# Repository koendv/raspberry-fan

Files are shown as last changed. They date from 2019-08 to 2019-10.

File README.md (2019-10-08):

# LTC1695 Raspberry Fan Controller

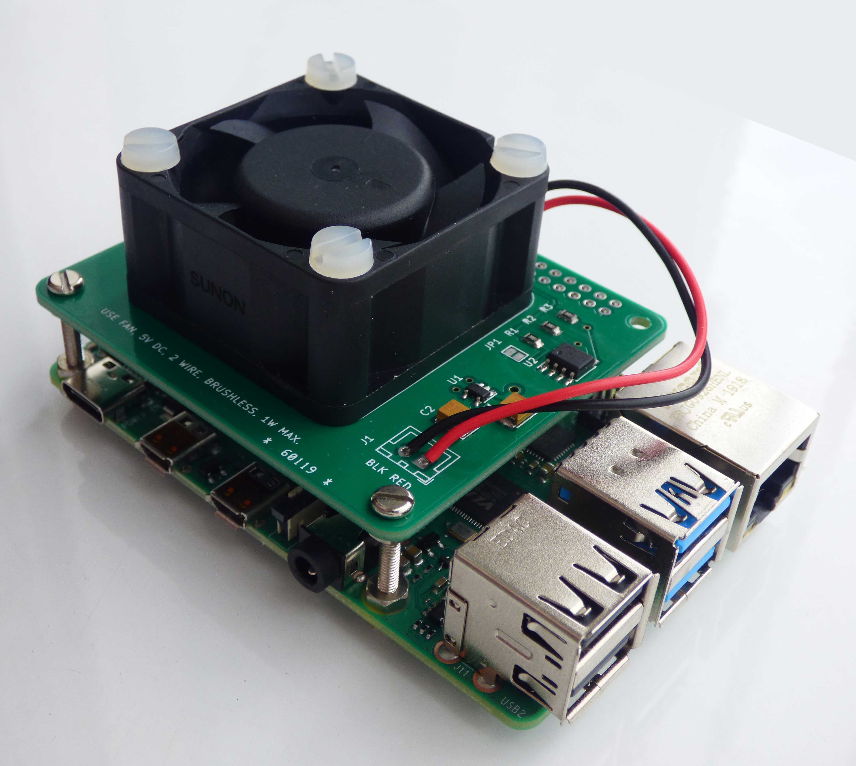
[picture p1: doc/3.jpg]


This is a fan speed controller for the Raspberry Pi. There is a smaller, cheaper version of the same controller [here](https://github.com/koendv/minimal_raspberry_fan).

## Hat

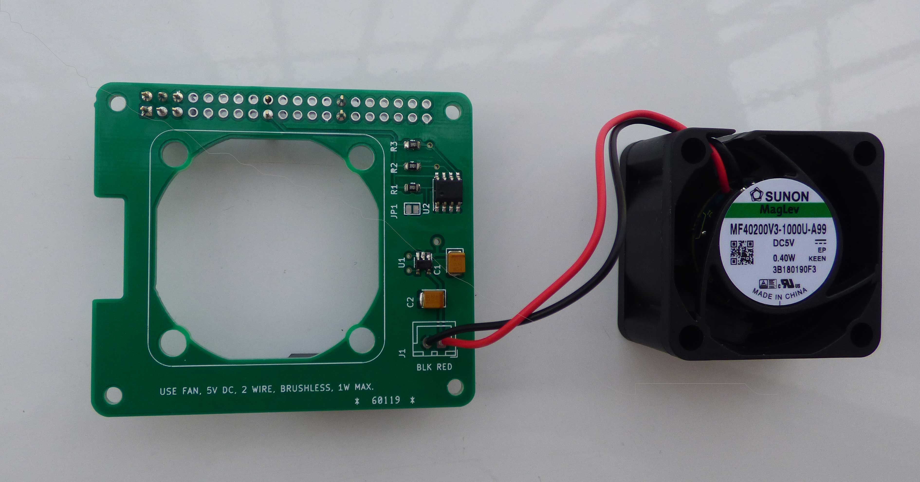
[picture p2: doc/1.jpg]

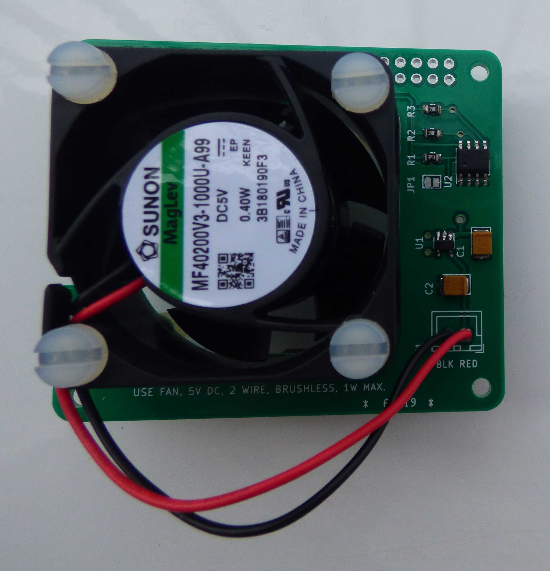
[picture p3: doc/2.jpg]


If you look at the [schematic](doc/schematic.pdf) you'll see the *hat* contains only two ic's: U1, an LTC1695 fan controller, and U2, a 24c32 EEPROM. The data in the EEPROM allows Raspbian to identify the hat. If you are making this for yourself, you can safely leave the EEPROM out.  That leaves us with the following components: 

Quant.|Item
---|--
1|LTC1695CS5  I2C Fan Speed Controller, SOT-23
2|KEMET T494B475K020AT Tantalum Capacitor, SMD 20V 4.7uF 1311 10% ESR=1 Ohms
1|Adafruit Accessories Header for Raspberry Pi
1|Sunon MF40200V3-1000U-A99 DC Fan 40mm, 5V.

The fan is 40mm, 5V DC, brushless, 2 wire, **1W max**. 
Adafruit has two GPIO headers for Raspberry, product numbers [1992](https://www.adafruit.com/product/1992) (tall, 16.5 mm) and  [2243](https://www.adafruit.com/product/2243) (short, 5.0 mm). Choose the one that clears the heatsink of the processor. 
## Installation
Enable i2c bus 1 clicking on the raspberry icon -> Preferences -> Raspberry Pi Configuration -> Interfaces -> i2c.
If you scan the i2c bus, you ought to see the fan controller at address 0x74:
```
koen@raspberrypi:~ $ sudo i2cdetect -r -y 1
     0  1  2  3  4  5  6  7  8  9  a  b  c  d  e  f
00:          -- -- -- -- -- -- -- -- -- -- -- -- -- 
10: -- -- -- -- -- -- -- -- -- -- -- -- -- -- -- -- 
20: -- -- -- -- -- -- -- -- -- -- -- -- -- -- -- -- 
30: -- -- -- -- -- -- -- -- -- -- -- -- -- -- -- -- 
40: -- -- -- -- -- -- -- -- -- -- -- -- -- -- -- -- 
50: -- -- -- -- -- -- -- -- -- -- -- -- -- -- -- -- 
60: -- -- -- -- -- -- -- -- -- -- -- -- -- -- -- -- 
70: -- -- -- -- 74 -- -- --                         
koen@raspberrypi:~ $ 
```
You can switch the fan completely on:
```
i2cset -y 1 0x74 63
```
completely off:
```
i2cset -y 1 0x74 0
```
or something in between:
```
i2cset -y 1 0x74 32
```
At low speeds, the fan might need a little extra push to get going. If you add 64 to the speed the fan will run at full speed for 0.25s, then slow down to the normal speed. As an example
```
i2cset -y 1 0x74 84
```
runs the  fan at the full 5V for a quarter second to get the fan moving, then drops to 1.56V for normal operation.

Lastly, you can read the fan controller status:
```
i2cget -y 1 0x74 
```

Value | Status
--------|--------
0|ok
64|thermal shutdown (T > 155 degree C)
128|overcurrent (I > 390mA)
192|thermal shutdown *and* overcurrent

## Running

The ```raspbian``` directory contains ```fanctl.py```, a python script which you can run either interactively or in the background. Feel free to modify the script as you wish. The values for *fan_min* and *fan_boost* are for the fan I'm using. The values  *temp_min* and *temp_max* represent personal choices. Once you are happy with the values, you can add the fan controller to ```/etc/rc.local``` so the fan starts up at boot:
```
/usr/local/bin/fanctl.py &
```

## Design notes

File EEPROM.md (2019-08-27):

# LTC1695 Raspberry Fan Controller

You can safely drop the EEPROM from the hat if you don't mind adding a daemon to /etc/rc.local yourself. Still, for those curious, this documents how to write the eeprom. 

## Writing the EEPROM
The fan controller is connected to i2c bus 1, while the configuration eeprom is connected to i2c bus 0. Enable i2c bus 1  in *Raspberry Pi Configuration -> Interfaces -> i2c*. To enable i2c bus 0 as well, add this line to /boot/config.txt and reboot:
```
dtparam=i2c_arm=on
dtparam=i2c_vc=on
```
Now you should be able to detect the configuration EEPROM on i2c bus 0, and the fan controller on i2c bus 1:
```
root@raspberrypi:/home/koen# i2cdetect -y 0
     0  1  2  3  4  5  6  7  8  9  a  b  c  d  e  f
00:          -- -- -- -- -- -- -- -- -- -- -- -- -- 
10: -- -- -- -- -- -- -- -- -- -- -- -- -- -- -- -- 
20: -- -- -- -- -- -- -- -- -- -- -- -- -- -- -- -- 
30: -- -- -- -- -- -- -- -- -- -- -- -- -- -- -- -- 
40: -- -- -- -- -- -- -- -- -- -- -- -- -- -- -- -- 
50: 50 -- -- -- -- -- -- -- -- -- -- -- -- -- -- -- 
60: -- -- -- -- -- -- -- -- -- -- -- -- -- -- -- -- 
70: -- -- -- -- -- -- -- --                         
root@raspberrypi:/home/koen# i2cdetect -y 1
     0  1  2  3  4  5  6  7  8  9  a  b  c  d  e  f
00:          -- -- -- -- -- -- -- -- -- -- -- -- -- 
10: -- -- -- -- -- -- -- -- -- -- -- -- -- -- -- -- 
20: -- -- -- -- -- -- -- -- -- -- -- -- -- -- -- -- 
30: -- -- -- -- -- -- -- -- -- -- -- -- -- -- -- -- 
40: -- -- -- -- -- -- -- -- -- -- -- -- -- -- -- -- 
50: -- -- -- -- -- -- -- -- -- -- -- -- -- -- -- -- 
60: -- -- -- -- -- -- -- -- -- -- -- -- -- -- -- -- 
70: -- -- -- -- 74 -- -- --                         
root@raspberrypi:/home/koen# 
```
To configure the EEPROM you need *eepromutils* from the Raspberry Pi [Hats github](https://github.com/raspberrypi/hats/tree/master/eepromutils). Compile these utilities. With these utilities, first compile the ascii description of the fan controller to binary:
```
eepmake  fan_eeprom_settings.txt fan_eeprom_settings.eep
```
On the fan controller next to the eeprom there's a small jumper  labeled "JP1". JP1 is the eeprom write protect jumper.  Close that jumper to enable writing the eeprom. Next write the  binary config file to the eeprom:
```
eepflash.sh -w -f=fan_eeprom_settings.eep -t=24c32 -d=0 -a=50
```
Remove the jumper on JP1. In ```/boot/config.txt``` comment out 
```
#dtparam=i2c_vc=on
```
and reboot. The hat identification data can now be found in /proc/device-tree/hat :
```
$ cat /proc/device-tree/hat/product
ltc1695 fan
```

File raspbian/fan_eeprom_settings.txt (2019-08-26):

########################################################################
# EEPROM settings text file
#
# Edit this file for your particular board and run through eepmake tool,
# then use eepflash tool to write to attached HAT ID EEPROM 
#
# Tools available:
#  eepmake   Parses EEPROM text file and creates binary .eep file
#  eepdump   Dumps a binary .eep file as human readable text (for debug)
#  eepflash  Write or read .eep binary image to/from HAT EEPROM
#
########################################################################

########################################################################
# Vendor info

# 128 bit UUID. If left at zero eepmake tool will auto-generate
# RFC 4122 compliant UUID
# product_uuid 00000000-0000-0000-0000-000000000000
product_uuid 3182e3cd-5004-4e2c-9e0f-2bacc548883b

# 16 bit product id
product_id 0x0001

# 16 bit product version
product_ver 0x0001

# ASCII vendor string  (max 255 characters)
vendor "kdv"

# ASCII product string (max 255 characters)
product "ltc1695 fan"

########################################################################
# GPIO bank settings, set to nonzero to change from the default.
# NOTE these setting can only be set per BANK, uncommenting any of
# these will force the bank to use the custom setting.

# drive strength, 0=default, 1-8=2,4,6,8,10,12,14,16mA, 9-15=reserved
gpio_drive 0

# 0=default, 1=slew rate limiting, 2=no slew limiting, 3=reserved
gpio_slew 0

# 0=default, 1=hysteresis disabled, 2=hysteresis enabled, 3=reserved
gpio_hysteresis 0

# If board back-powers Pi via 5V GPIO header pins:
# 0 = board does not back-power
# 1 = board back-powers and can supply the Pi with a minimum of 1.3A
# 2 = board back-powers and can supply the Pi with a minimum of 2A
# 3 = reserved
# If back_power=2 then USB high current mode will be automatically 
# enabled on the Pi
back_power 0

########################################################################
# GPIO pins, uncomment for GPIOs used on board
# Options for FUNCTION: INPUT, OUTPUT, ALT0-ALT5
# Options for PULL: DEFAULT, UP, DOWN, NONE
# NB GPIO0 and GPIO1 are reserved for ID EEPROM so cannot be set

#         GPIO  FUNCTION  PULL
#         ----  --------  ----
setgpio  2     INPUT     DEFAULT
setgpio  3     INPUT     DEFAULT
#setgpio  4     INPUT     DEFAULT
#setgpio  5     INPUT     DEFAULT
#setgpio  6     INPUT     DEFAULT
#setgpio  7     INPUT     DEFAULT
#setgpio  8     INPUT     DEFAULT
#setgpio  9     INPUT     DEFAULT
#setgpio  10    INPUT     DEFAULT
#setgpio  11    INPUT     DEFAULT
#setgpio  12    INPUT     DEFAULT
#setgpio  13    INPUT     DEFAULT
#setgpio  14    INPUT     DEFAULT
#setgpio  15    INPUT     DEFAULT
#setgpio  16    INPUT     DEFAULT
#setgpio  17    INPUT     DEFAULT
#setgpio  18    INPUT     DEFAULT
#setgpio  19    INPUT     DEFAULT
#setgpio  20    INPUT     DEFAULT
#setgpio  21    INPUT     DEFAULT
#setgpio  22    INPUT     DEFAULT
#setgpio  23    INPUT     DEFAULT
#setgpio  24    INPUT     DEFAULT
#setgpio  25    INPUT     DEFAULT
#setgpio  26    INPUT     DEFAULT
#setgpio  27    INPUT     DEFAULT

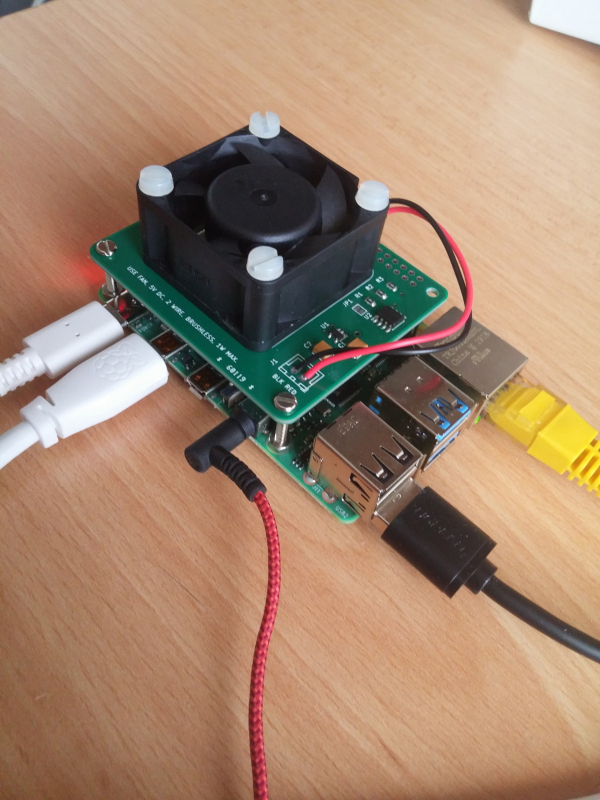
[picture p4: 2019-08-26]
doc/fan1.jpg

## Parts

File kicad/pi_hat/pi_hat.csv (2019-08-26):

Title | Raspberry Fan Speed Controller
Revision | 0
Date | 2019-03-09
Generated | Wed 13 Mar 2019 08:39:04 PM CET
Company
Comment 1
Comment 2
Comment 3
Comment 4
Total Parts | 18
Total Unique Parts | 9
Ref | Qty | Value | Footprint | Mouser ref no | price EUR
C2 C1 | 2 | 4u7 20V ESR 1R | Capacitor_Tantalum_SMD:CP_EIA-3528-12_Kemet-T | 80-T494B475K020 | 0.681 | 1.362
H1 H3 H2 H4 | 4 | M4 | MountingHole:MountingHole_4.3mm_M4
J1 | 1 | Conn_01x02 | Connector_JST:JST_XH_B02B-XH-A_1x02_P2.50mm_Vertical | 538-99-99-0986 | 0.45 | 0.45 | JST B2B-XH-A (LF)(SN) 2nd source: Molex 99-99-0986.
JP1 | 1 | Write Enable | Jumper:SolderJumper-2_P1.3mm_Open_Pad1.0x1.5mm
MK1 MK3 MK2 MK4 | 4 | M2.5 | MountingHole:MountingHole_2.7mm_M2.5
P1 | 1 | Conn_02x20_Odd_Even | Connector_PinSocket_2.54mm:PinSocket_2x20_P2.54mm_Vertical | 485-2223 | 2.18 | 2.18
R1 R2 R3 | 3 | 3k9 | Resistor_SMD:R_0805_2012Metric | 667-ERJ-6ENF3901V | 0.087 | 0.261
U1 | 1 | LTC1695CS5 | Package_TO_SOT_SMD:TSOT-23-5 | LTC1695CS5#TRMPBF | 3.34 | 3.34
U2 | 1 | CAT24C32 | Package_SO:SOIC-8_3.9x4.9mm_P1.27mm | 698-CAT24C32WI-GT3 | 0.41 | 0.41
FAN | 1 | FAN | FAN,40x40mm, 5V DC, 2 wire, 1W max. | MF40200V3-1000U-A99 | 5.93 | 5.93 | Sunon MF40200V3-1000U-A99
 |  |  |  |  |  | 13.933
BOM made with KICAD_BOM_WIZARD (https://github.com/HashDefineElectronics/KiCad_BOM_Wizard.git)
Generated Wed 13 Mar 2019 08:39:04 PM CET
 |  |  | Connector J1 can be omitted if fan wires are soldered directly to the pcb.
 |  |  | Comparison of fans:
 |  |  | Model | Airflow | Power | Noise | Revolutions | Pressure
 |  |  | Sunon MF40200V3-1000U-A99 | 6.3CFM | 0.38W | 16.5dBA | 5000RPM | 0.11inch H2O | quietest, smallest airflow
 |  |  | Sunon MF40100V2-1000U-A99 | 7CFM | 0.47W | 20.6dBA | 5800RPM | 0.12inch H2O
 |  |  | Sunon MF40200V2-1000U-A99 | 7.7CFM | 0.54W | 21dBA | 6000RPM | 0.17inch H2O
 |  |  | Sunon MF40200V1-1000U-A99 | 8.9CFM | 0.75W | 25.5dBA | 7000RPM | 0.22inch H2O | loudest, biggest airflow

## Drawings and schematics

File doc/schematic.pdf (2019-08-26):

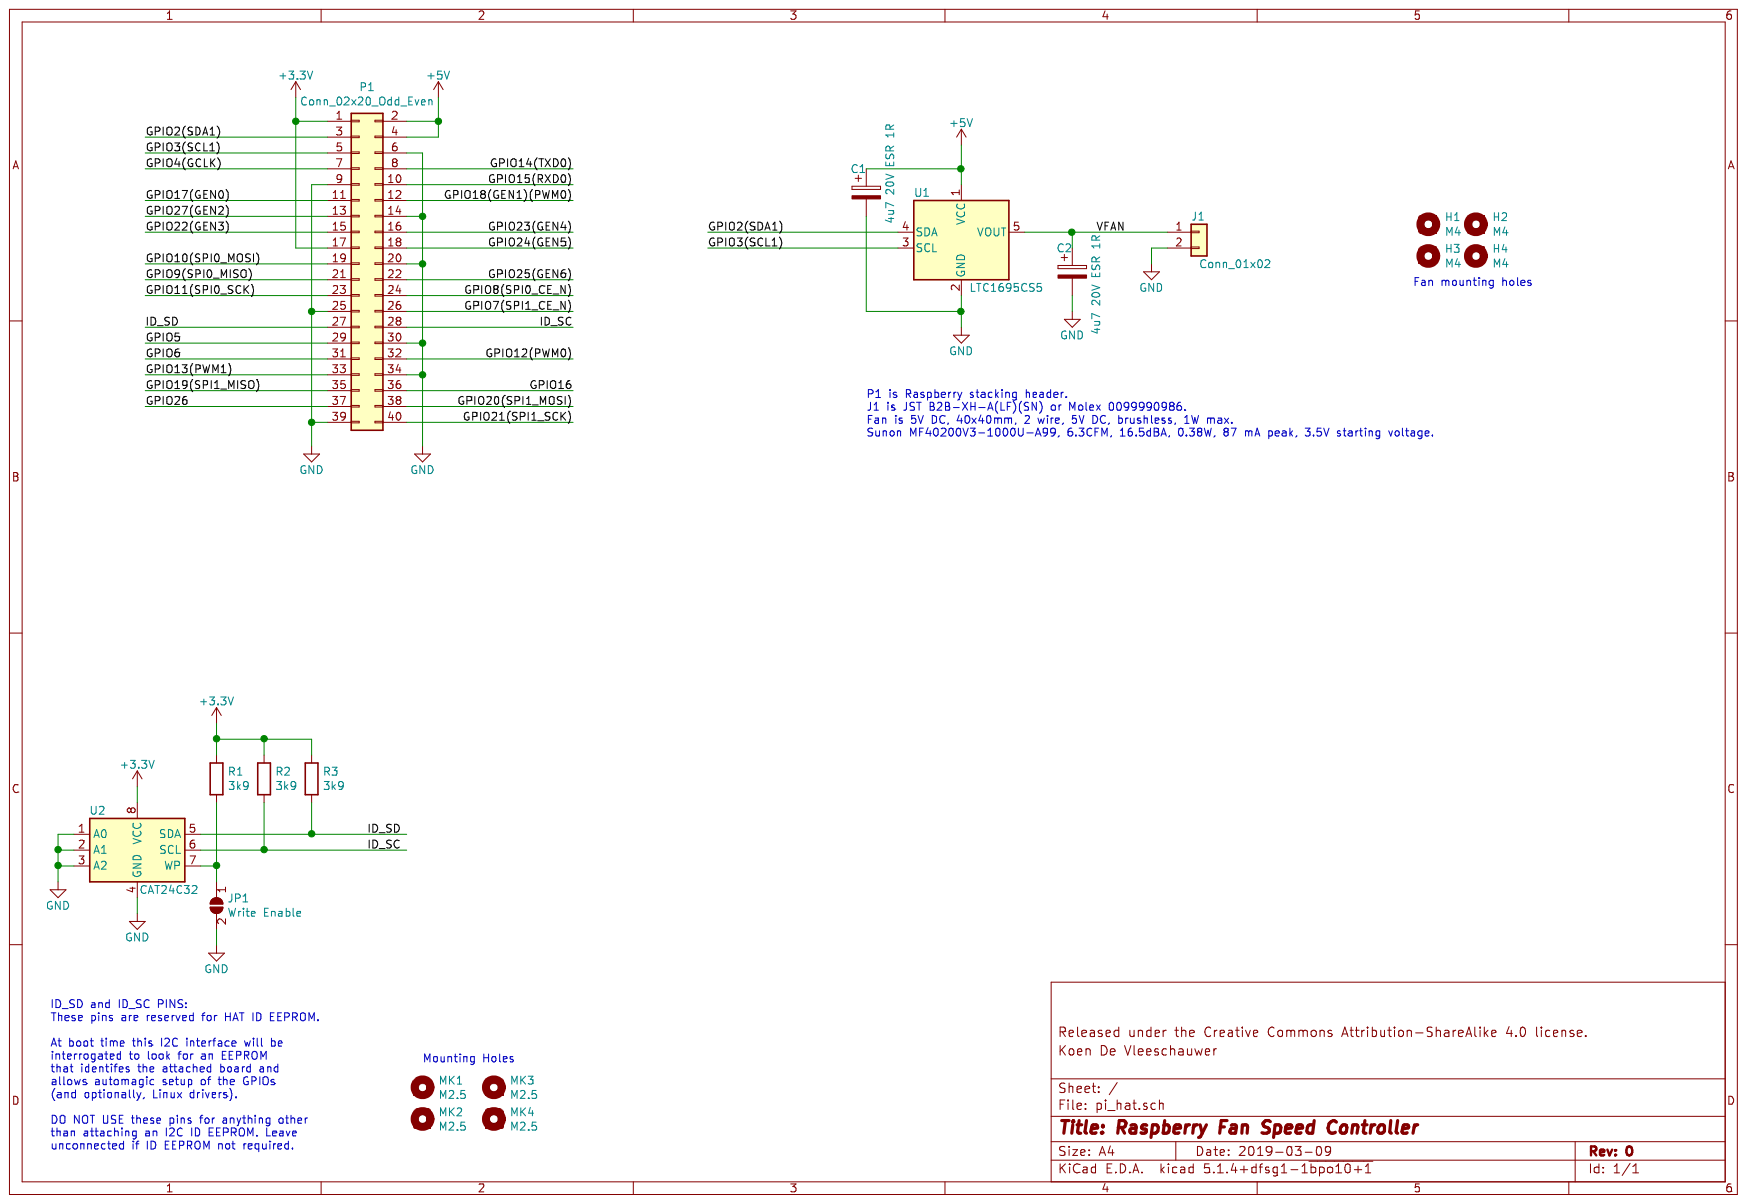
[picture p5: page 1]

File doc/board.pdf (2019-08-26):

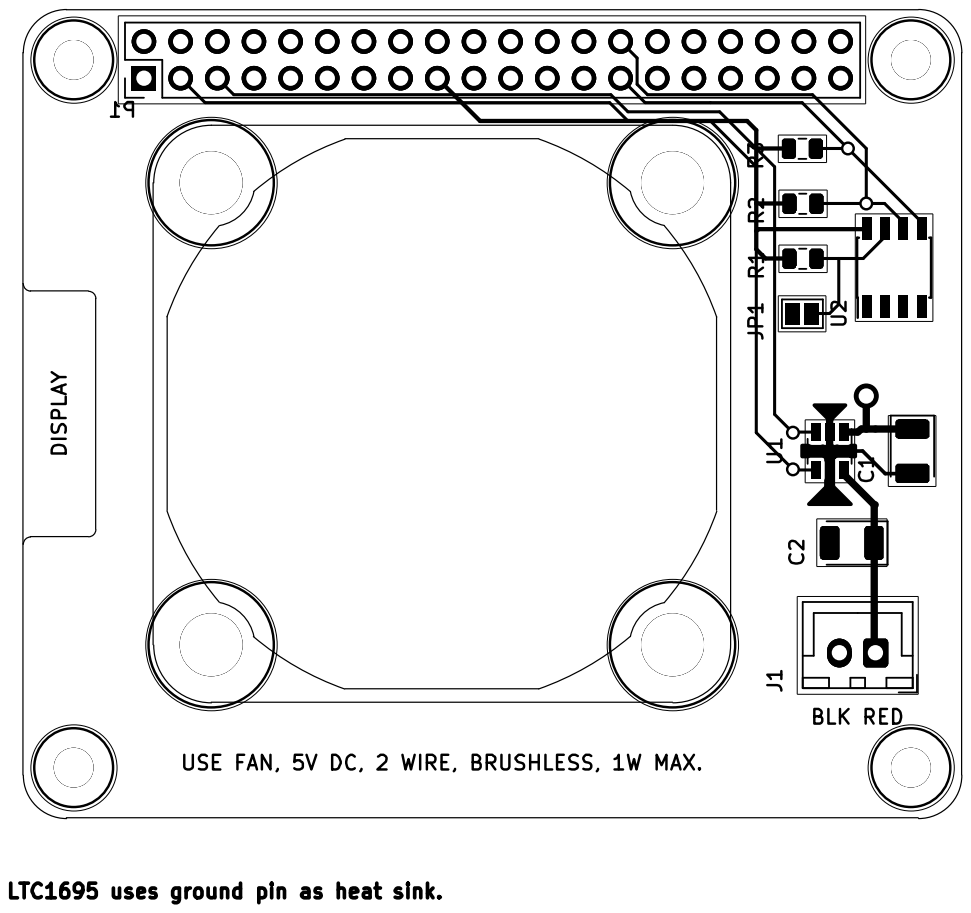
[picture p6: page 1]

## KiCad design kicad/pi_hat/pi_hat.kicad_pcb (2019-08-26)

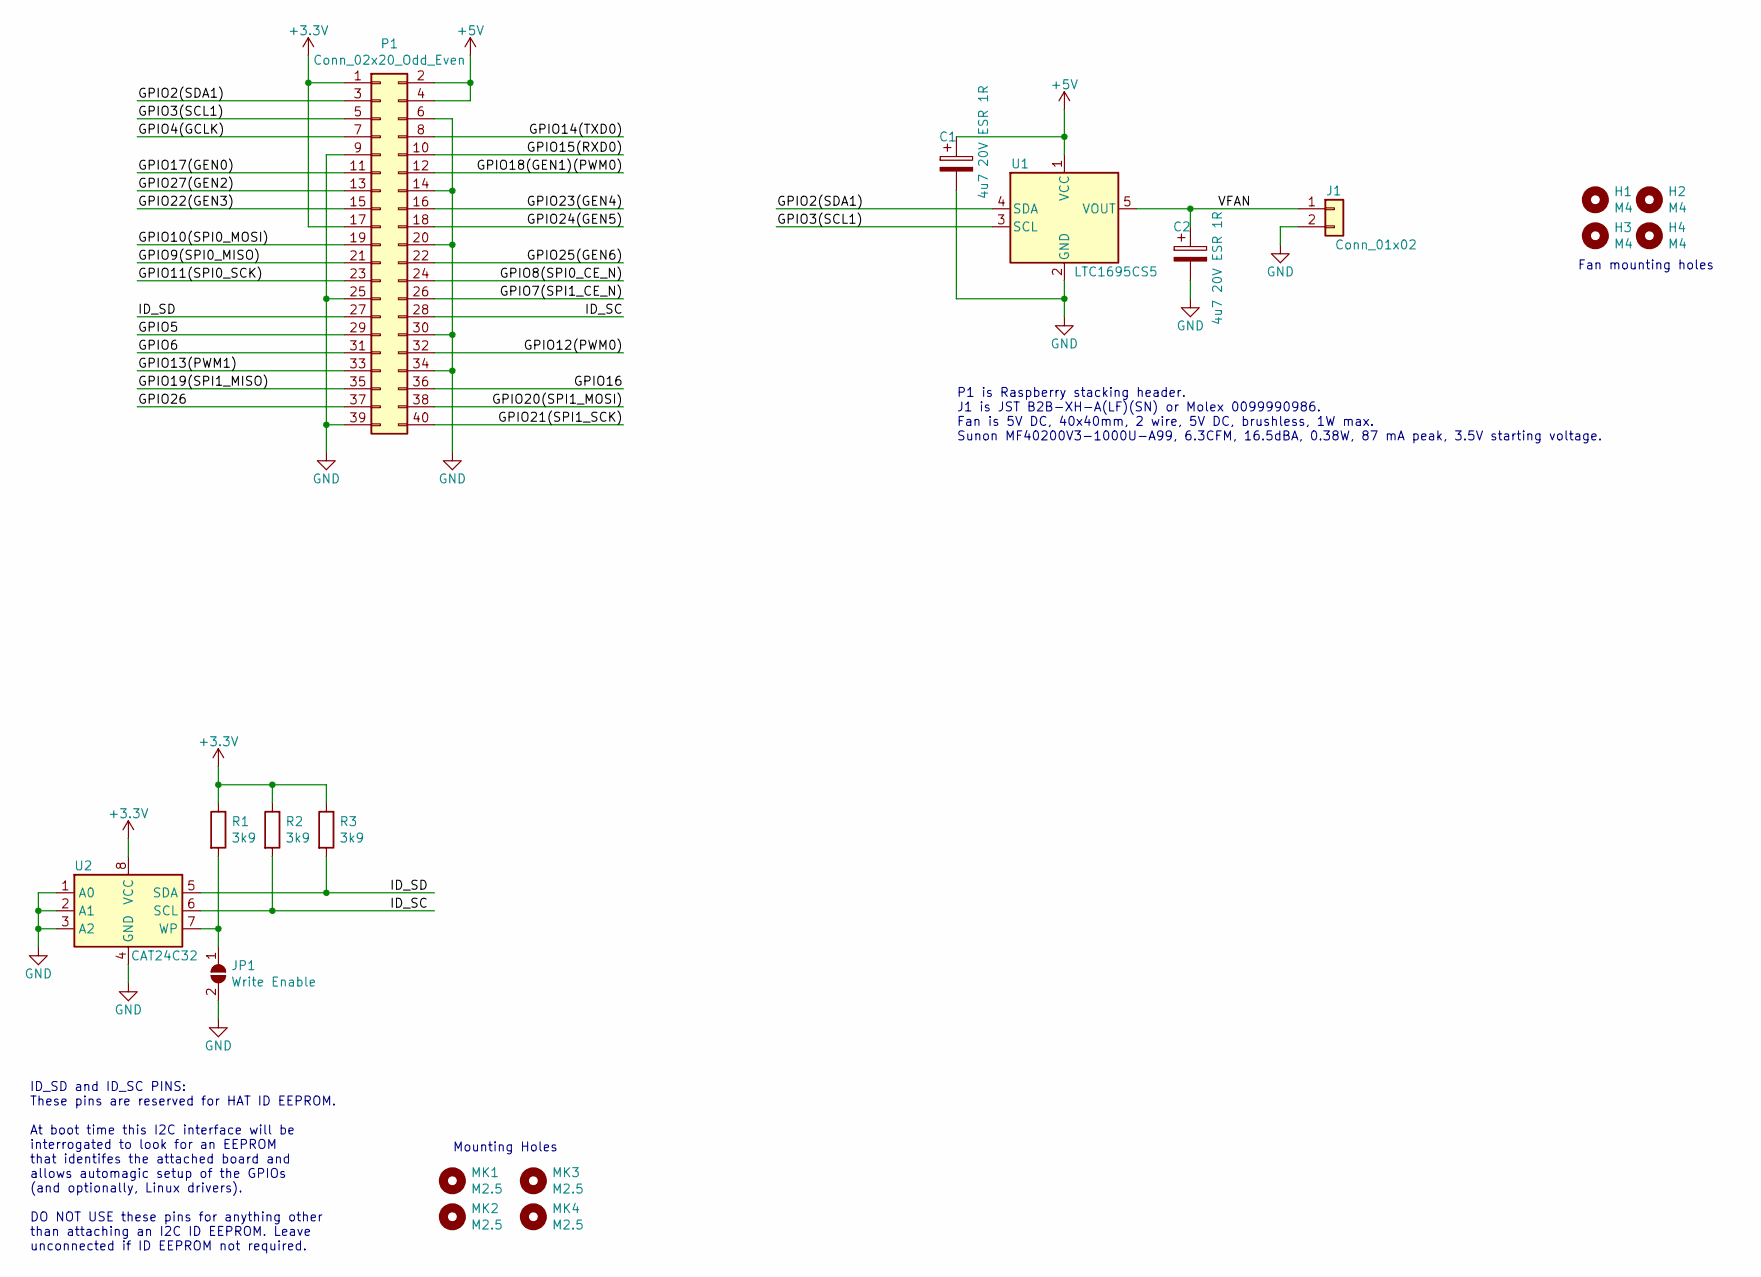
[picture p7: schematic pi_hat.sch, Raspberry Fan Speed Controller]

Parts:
C1, C2: 4u7 20V ESR 1R; CP_EIA-3528-12_Kemet-T
H1, H2, H3, H4: M4; MountingHole_4.3mm_M4
J1: Conn_01x02; JST_XH_B02B-XH-A_1x02_P2.50mm_Vertical
JP1: Write Enable; SolderJumper-2_P1.3mm_Open_Pad1.0x1.5mm
MK1, MK2, MK3, MK4: M2.5; MountingHole_2.7mm_M2.5
P1: Conn_02x20_Odd_Even; PinSocket_2x20_P2.54mm_Vertical
R1, R2, R3: 3k9; R_0805_2012Metric
U1: LTC1695CS5; TSOT-23-5
U2: CAT24C32; SOIC-8_3.9x4.9mm_P1.27mm

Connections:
+3V3: P1.1, P1.17, R1.1, R2.1, R3.1, U2.8 (VCC)
+5V: C1.1, P1.2, P1.4, U1.1 (VCC)
/GPIO2(SDA1): P1.3, U1.4 (SDA)
/GPIO3(SCL1): P1.5, U1.3 (SCL)
/GPIO4(GCLK): P1.7
/GPIO5: P1.29
/GPIO6: P1.31
/GPIO7(SPI1_CE_N): P1.26
/GPIO8(SPI0_CE_N): P1.24
/GPIO9(SPI0_MISO): P1.21
/GPIO10(SPI0_MOSI): P1.19
/GPIO11(SPI0_SCK): P1.23
/GPIO12(PWM0): P1.32
/GPIO13(PWM1): P1.33
/GPIO14(TXD0): P1.8
/GPIO15(RXD0): P1.10
/GPIO16: P1.36
/GPIO17(GEN0): P1.11
/GPIO18(GEN1)(PWM0): P1.12
/GPIO19(SPI1_MISO): P1.35
/GPIO20(SPI1_MOSI): P1.38
/GPIO21(SPI1_SCK): P1.40
/GPIO22(GEN3): P1.15
/GPIO23(GEN4): P1.16
/GPIO24(GEN5): P1.18
/GPIO25(GEN6): P1.22
/GPIO26: P1.37
/GPIO27(GEN2): P1.13
/ID_SC: P1.28, R2.2, U2.6 (SCL)
/ID_SD: P1.27, R3.2, U2.5 (SDA)
/VFAN: C2.1, J1.1, U1.5 (VOUT)
GND: C1.2, C2.2, J1.2, JP1.2 (B), P1.6, P1.9, P1.14, P1.20, P1.25, P1.30, P1.34, P1.39, U1.2 (GND), U2.1 (A0), U2.2 (A1), U2.3 (A2), U2.4 (GND)
unnamed: JP1.1 (A), R1.2, U2.7 (WP)

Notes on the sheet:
ID_SD and ID_SC PINS: These pins are reserved for HAT ID EEPROM. At boot time this I2C interface will be interrogated to look for an EEPROM that identifes the attached board and allows automagic setup of the GPIOs (and optionally, Linux drivers). DO NOT USE these pins for anything other than attach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
Mounting Holes
Fan mounting holes
P1 is Raspberry stacking header. J1 is JST B2B-XH-A(LF)(SN) or Molex 0099990986. Fan is 5V DC, 40x40mm, 2 wire, 5V DC, brushless, 1W max. Sunon MF40200V3-1000U-A99, 6.3CFM, 16.5dBA, 0.38W, 87 mA peak, 3.5V starting voltage.

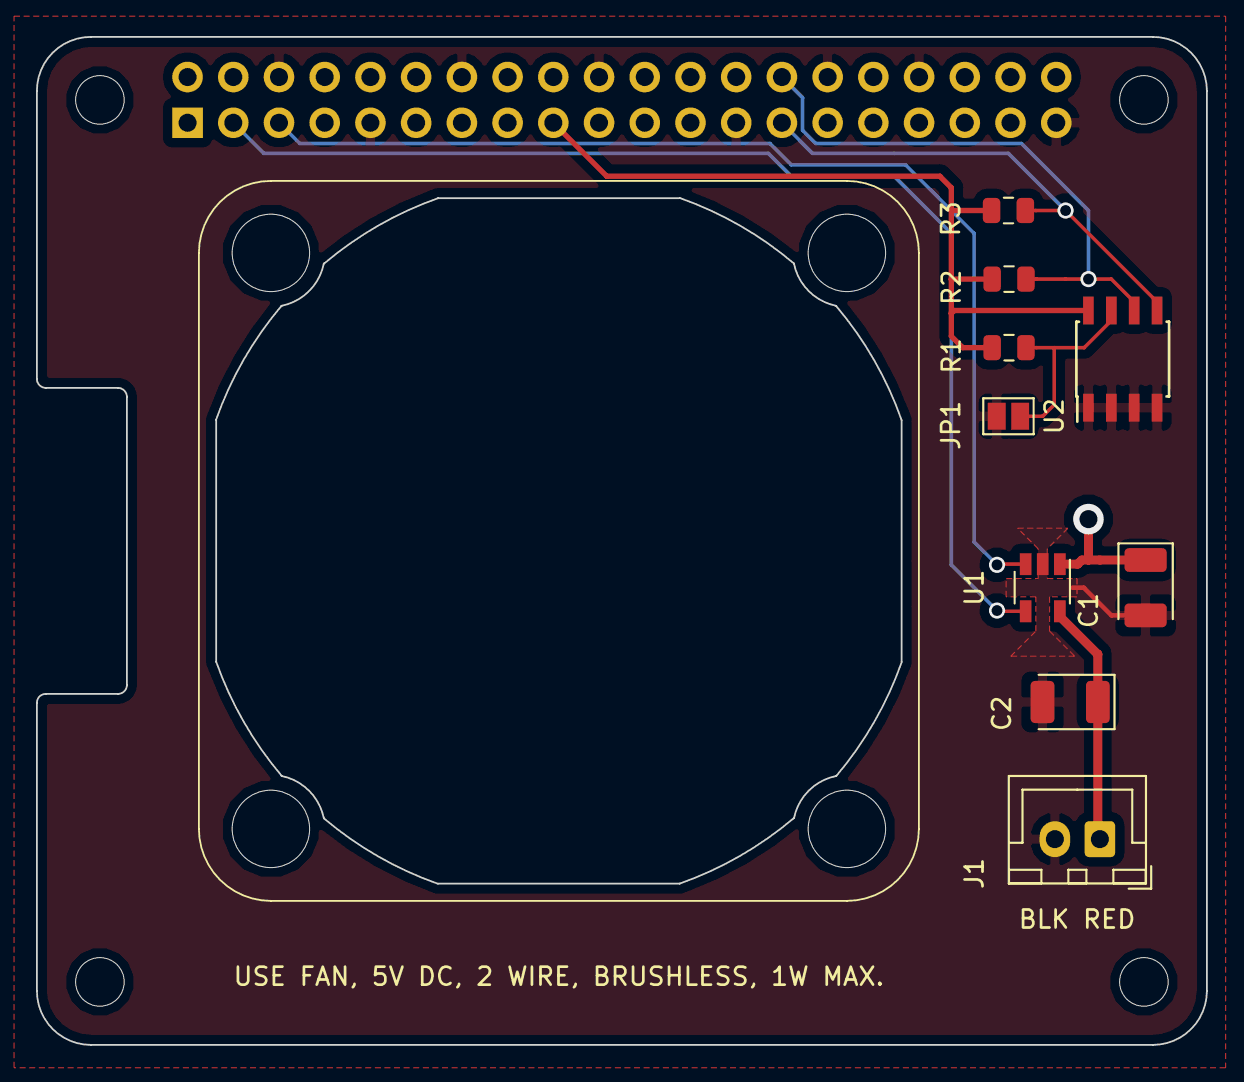
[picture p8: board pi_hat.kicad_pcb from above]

Board: 2 copper layers, 65.0 x 56.0 mm, 18 parts (0 on the bottom side), 9 nets.

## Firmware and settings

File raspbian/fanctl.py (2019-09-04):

#!/usr/bin/python3
#
# Utility for ltc1695 fan controller
# CC0 Koen De Vleeschauwer 2019
#
# to start up at boot, in /etc/rc.local add:
# /usr/local/bin/fanctl &
#

import os
import re
from time import sleep
import signal
import sys
import smbus

ltc1695_bus = 1
ltc1695_address = 0x74

fan_min = 20   # min fan speed
fan_boost = 25 # lowest speed where fan is guaranteed to start
fan_max = 63   # max fan speed

temp_min = 60  # min temperature
temp_max = 80  # max temperature

soft_start = False # soft or hard start
debug = False

# get cpu and video temperature

def get_cpu_temperature():
    tFile = open('/sys/class/thermal/thermal_zone0/temp')
    temp_millis = '00000' + tFile.read()
    temp = int(temp_millis[:-4])
    if debug:
        print ("cpu temp:", temp)
    return temp

def get_video_temperature():
    video_temp = os.popen("vcgencmd measure_temp").readline()
    temp = int(re.findall("\d+", video_temp + '0')[0])
    if debug:
        print ("video temp:", temp)
    return temp

# i2c write and read to fan controller

def get_fan():
    fan_status = bus.read_byte(ltc1695_address)
    if fan_status & 0x80:
        print("overcurrent")
    if fan_status & 0x40:
        print("thermal shutdown")
    return()

def set_fan(speed, boost):
    dta = int(speed)
    if not dta in range(0, 64):
        return()
    if boost:
        dta += 64;
    bus.write_byte(ltc1695_address, dta)
    return()

# set fan speed
# to avoid stalling at low speeds, if the fan speed is less than or equal to fan_boost
# the fan will run at full speed for a quarter of a second, and then continue at the programmed speed ("boost")

def set_fan_speed(speed):
    global fan_running
    if speed > fan_max:
        speed = fan_max
    elif speed < 0:
        speed = 0
    boost = not fan_running and speed > 0 and speed < fan_boost
    # if soft_boost is configured, we first run 0.25s at fan_boost
    if boost & soft_start:
        set_fan(fan_boost, False)
        sleep(0.25)
        boost = False
    set_fan(speed, boost)
    fan_running = speed >= fan_min
    if debug:
        print ("fan speed: ", speed)
    return()

def fan_off():
    set_fan_speed(0)
    return()

# main loop
#
# fan speed ramps up linearly from fan_min to fan_max when temperature goes from temp_min to temp_max

def loop():
    get_fan()
    temp = max(get_cpu_temperature(), get_video_temperature())
    if temp < temp_min:
        speed = 0
    else:
        speed = int((temp - temp_min) * (fan_max - fan_min) / (temp_max - temp_min) + fan_min)
    set_fan_speed(speed)
    return()

# main

if len(sys.argv) == 2 and sys.argv[1] == "-t":
    # print temp
    debug = True
    get_cpu_temperature()
    get_video_temperature()
    exit()

if os.geteuid() != 0:
    exit("Are you root?")

fan_running = False
bus = smbus.SMBus(ltc1695_bus)

if len(sys.argv) == 2 and sys.argv[1].isdigit():
    # set fan speed
    speed = int(sys.argv[1])
    set_fan_speed(speed)
    get_fan()
    exit()
elif len(sys.argv) == 2 and sys.argv[1] == "-d":
    # switch on debugging
    debug = True
elif len(sys.argv) != 1:
    print("Usage: fanctrl [-d] [-t] [speed]")
    print("where speed = 0 .. 63")
    exit()

try:
    while True:
        loop()
        sleep(57) # choose largest prime number smaller than 60 in case some job starts up every minute
except KeyboardInterrupt:
    fan_off()

# not truncated

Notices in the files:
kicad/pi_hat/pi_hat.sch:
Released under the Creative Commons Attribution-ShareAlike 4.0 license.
